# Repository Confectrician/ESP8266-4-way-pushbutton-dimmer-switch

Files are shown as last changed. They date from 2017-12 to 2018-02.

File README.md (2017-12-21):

# ESP8266 4-Way Pushbutton Dimmer Switch

This is a project that uses 4 inputs on a Wemos D1 Mini, to interact as pushbutton, switch or dimmer over mqtt.
It is based on [homie convention](https://github.com/marvinroger/homie) and uses the [homie-esp8266](https://github.com/marvinroger/homie-esp8266) framework.

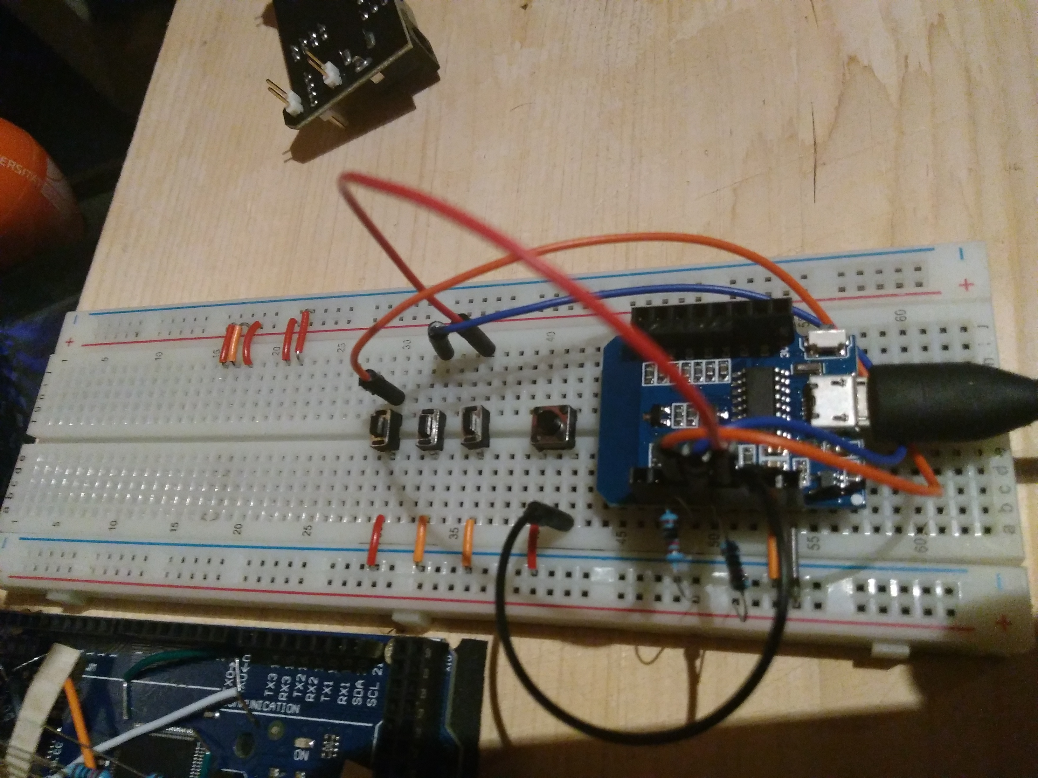
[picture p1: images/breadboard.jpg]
Breadboard test setup


## Concepts

According to the convention our topic will start with `base/decive-id` like it has been configured.

From here every pushbutton has its own main topic, which can be configured individually in `constants.h` for every pushbutton.
You can also configure the `NODE_TYPE` here for the device meta informations, that homie provides.

Every pushbutton has 3 functional mqqt topics configured.

- `pressed` indicates if the pushbutton is pressed currently
- `switchState` provides a switchmode, which will alternate between `true` and `false`
- `dimmerValue` provides a value between `0` and `100`

An example topic would for a dimmerValue would then be `homie/livingroom-multidimmer/pushbutton1/dimmerValue`.

The pushbuttons will react different depending on the time they have been pushed.
Short push actions will be interpreted as a *tap-action* and just affect the *switchState* topic.
Longer push actions will be interpreted as a *dimm-action* and change the *dimmerValue*.
The  *dimmerValue* is *increased* or *decreased* depending on the *switchState* **and** the current *dimmerValue* itself.

- *increased* when
`switchState` is LOW/false and the current `dimmerValue` is lower than or equal to `100`

- *decreased* when
`switchState` is HIGH/true and the current `dimmerValue` is greater than or equal to `0`

## Hardware

> partly tbd - just a testing setup @ the moment

- Wemos D1 Mini
- 4 pushbuttons of your choice to connect to the pcb
- 2 10kΩ resistors (see pinout information)
- Conectors with 0.2in/5.08mm space between the pins
- A DC source of your choice to power up the Wemos

### Custom PCB

tbd

### Pinout Information (Wemos D1 Mini)

Please be aware that only pin D3 and D4 have an integrated Pull up resistor.
For the other pins of your choice, you will have to add a 10kΩ pullup resistor to each input.

Also keep in mind that pin D3 is able to reset your device.
Make sure that `Homie.disableResetTrigger();` is called in the `setup()` function befor `Homie.setup()` is called.

## Pushbutton to dimmer handling

### Compare dimmer to pushbutton input

Caution. The following paragraph could be a bit *geeky*.

After some *practical research* the average time for one **button push to button release event** is about `247,4285714ms`.
Minimum time needed was `191ms`.
Maximum time needed was `287ms`.

Based on this values, i have set the `DIMMER_PUSH_INTERVAL` to `300ms` for now.
This value is used to decide wether a push is hold to start a dimmer or just tapped to update the `switchState`.

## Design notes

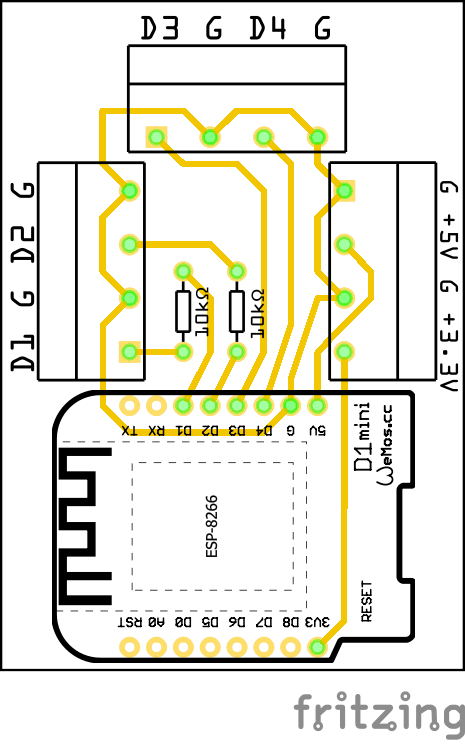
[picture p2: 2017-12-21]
images/pcb.png

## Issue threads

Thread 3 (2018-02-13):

Change PCB Design for direct connection to the main voltage.

Confectrician, 2018-02-13:
There are several pcb parts available to transform 203V AC into 5V DC.
Version 2 should include such a device, to connect it to the main voltage installation directly

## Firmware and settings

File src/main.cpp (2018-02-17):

/*
    main.cpp - Library for ESP8266 4 way pushbutton dimmer switch project
    Creadted by Jerome Luckenbach, 2017-12-08
    Released under MIT License
*/
#include <Homie.h>
#include <pushbutton.h>
#include <constants.h>
#include <pins.h>

// Pin config
const int pushbutton1Pin = PUSHBUTTON1_PIN; // Caution -> 10k pullup needed here
const int pushbutton2Pin = PUSHBUTTON2_PIN; // Caution -> 10k pullup needed here
const int pushbutton3Pin = PUSHBUTTON3_PIN;
const int pushbutton4Pin = PUSHBUTTON4_PIN;

// Button meta variables
// TODO Maybe let pushButton inherit from HomieNode, to keep all metadata in one class
pushButton pushButton1;
pushButton pushButton2;
pushButton pushButton3;
pushButton pushButton4;

// Node instances
HomieNode pushbutton1Node(NODE_1, NODE_TYPE);
HomieNode pushbutton2Node(NODE_2, NODE_TYPE);
HomieNode pushbutton3Node(NODE_3, NODE_TYPE);
HomieNode pushbutton4Node(NODE_4, NODE_TYPE);

// function declarations
bool globalInputHandler(const HomieNode& node, const String& property, const HomieRange& range, const String& value);
void checkPushButton(const HomieNode& node, const int& reading, int& state, int& lastReading);
void loopHandler();


void setup() {
    Serial.begin(115200);
    Serial << endl << endl;

    // Hardware configuration
    pinMode(pushbutton1Pin, INPUT);
    pinMode(pushbutton2Pin, INPUT);
    pinMode(pushbutton3Pin, INPUT);
    pinMode(pushbutton4Pin, INPUT);

    digitalWrite(pushbutton1Pin, HIGH);
    digitalWrite(pushbutton2Pin, HIGH);
    digitalWrite(pushbutton3Pin, HIGH);
    digitalWrite(pushbutton4Pin, HIGH);
    
    // Debouncer configuration
    pushButton1.debouncer.attach(pushbutton1Pin);
    pushButton2.debouncer.attach(pushbutton2Pin);
    pushButton3.debouncer.attach(pushbutton3Pin);
    pushButton4.debouncer.attach(pushbutton4Pin);

    pushButton1.debouncer.interval(DEBOUNCE_INTERVAL);
    pushButton2.debouncer.interval(DEBOUNCE_INTERVAL);
    pushButton3.debouncer.interval(DEBOUNCE_INTERVAL);
    pushButton4.debouncer.interval(DEBOUNCE_INTERVAL);


    // Homie configuration
    Homie_setFirmware("4-way-pushbutton-dimmer-switch", "1.0.2"); 
    Homie.disableResetTrigger(); // Needed to prevent resetting the device by mistake, since we are using D3 input.
    Homie.setGlobalInputHandler(globalInputHandler);
    Homie.setLoopFunction(loopHandler);

    // Node configurations
    pushbutton1Node.advertise("pressed");
    pushbutton2Node.advertise("pressed");
    pushbutton3Node.advertise("pressed");
    pushbutton4Node.advertise("pressed");

    pushbutton1Node.advertise("switchState").settable();
    pushbutton2Node.advertise("switchState").settable();
    pushbutton3Node.advertise("switchState").settable();
    pushbutton4Node.advertise("switchState").settable();

    pushbutton1Node.advertise("dimmerValue").settable();
    pushbutton2Node.advertise("dimmerValue").settable();
    pushbutton3Node.advertise("dimmerValue").settable();
    pushbutton4Node.advertise("dimmerValue").settable();

    Homie.setup();
}

void loop() {
    Homie.loop();
    pushButton1.debouncer.update();
    pushButton2.debouncer.update();
    pushButton3.debouncer.update();
    pushButton4.debouncer.update();
}

void checkPushButton(const HomieNode& node, const int& reading, pushButton& button){
    
    // pushbutton stated changed
    if(reading != button.lastReading){

        Homie.getLogger() << node.getId() << " changed on " << millis() << " millis" << endl;        
        node.setProperty("pressed").send(reading ? "false" : "true");

        // update switchState when the pushbutton is released and was pushed not later than DIMMER_PUSH_INTERVAL
        if(reading == HIGH && button.lastReading== LOW && (millis() - button.lastReadingTime < DIMMER_PUSH_INTERVAL)){

            node.setProperty("switchState").send(button.switchState ? "false" : "true");
            node.setProperty("dimmerValue").send(button.switchState ? "0" : "100");

            button.dimmerValue = button.switchState? 0 : 100;
            button.switchState = button.switchState ? LOW : HIGH;
            
        }

        button.lastReading = reading;
        button.lastReadingTime = millis();
    }
    // pushbutton state is consant. 
    else if(reading == button.lastReading){

        // start dimmerModer when DIMMER_PUSH_INTERVAL time has reached and button is pressed
        if(!button.dimmerMode && reading == LOW && (millis() - button.lastReadingTime) > DIMMER_PUSH_INTERVAL){
            button.dimmerMode = true;
            button.dimmerReadingTime = button.lastReadingTime;            
        }

        if(button.dimmerMode){
            // start dimmer action when DIMMER_CONTINUE_INTERVAL time has reached and button is pressed
            if(reading == LOW && (millis() - button.dimmerReadingTime) > DIMMER_CONTINUE_INTERVAL){    
                
                if(button.switchState == LOW && button.dimmerValue <= 100){
                    button.dimmerValue += DIMMER_STEP_VALUE;
                    node.setProperty("dimmerValue").send(String(button.dimmerValue));

                    if(button.dimmerValue == 100){
                        node.setProperty("switchState").send("true");
                        button.switchState = HIGH;
                    }
                }
                else if(button.switchState == HIGH && button.dimmerValue >= 0){
                    button.dimmerValue -= DIMMER_STEP_VALUE;
                    node.setProperty("dimmerValue").send(String(button.dimmerValue));

                    if(button.dimmerValue == 0){
                        node.setProperty("switchState").send("false");
                        button.switchState = LOW;
                    }
                }

                Homie.getLogger() << "--> " << node.getId() << "dimmer action processed. DimmerValue = " << button.dimmerValue << endl;
                button.dimmerReadingTime = millis();

            }
            // stop dimmerMode when pushbutton is released 
            else if (reading == HIGH) {
                button.dimmerMode = false;
            }
        }

    }
}

bool globalInputHandler(const HomieNode& node, const String& property, const HomieRange& range, const String& value) {

    Homie.getLogger() << "Received on node " << node.getId() << ": " << property << " = " << value << endl;

    if(property == "switchState" && (value == "true" || value == "false")){

        Homie.getLogger() << "Property and value are valid. Checking for the correct Node now." << endl;
        
        if(node.getId() == "pushbutton1"){
            pushButton1.switchState = (value == "true") ? HIGH : LOW;
        } else if(node.getId() == "pushbutton2"){
            pushButton2.switchState = (value == "true") ? HIGH : LOW;
        } else if(node.getId() == "pushbutton3"){
            pushButton3.switchState = (value == "true") ? HIGH : LOW;
        } else if(node.getId() == "pushbutton4"){
            pushButton4.switchState = (value == "true") ? HIGH : LOW;            
        } else {
            return false; // Unknown Node. Return unhandled            
        }

        // Update the Property only, when any of the if cases has been handled.
        node.setProperty("switchState").send((value == "true") ?  "true" : "false");
        return true;
    }

    return false;
}

void loopHandler(){

    checkPushButton(pushbutton1Node, pushButton1.debouncer.read(), pushButton1);
    checkPushButton(pushbutton2Node, pushButton2.debouncer.read(), pushButton2);
    checkPushButton(pushbutton3Node, pushButton3.debouncer.read(), pushButton3);
    checkPushButton(pushbutton4Node, pushButton4.debouncer.read(), pushButton4);

}

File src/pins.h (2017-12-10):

/*
    pins.h - Library for ESP8266 4 way pushbutton dimmer switch project
    Creadted by Jerome Luckenbach, 2017-12-10
    Released under MIT License
*/

#ifndef FWPB_Pins_h
#define FWPB_Pins_h

// circuit pin definitions
#define PUSHBUTTON1_PIN D1 // Caution -> 10k pullup needed here
#define PUSHBUTTON2_PIN D2 // Caution -> 10k pullup needed here
#define PUSHBUTTON3_PIN D3
#define PUSHBUTTON4_PIN D4

#endif

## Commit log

2017-12-21 Added pcb file and image. Updated readme
    [Wemos 4 Fach Taster.fzz]
2018-02-17 OTA Update Test + Layout changes
    [Wemos 4 Fach Taster.fzz]
